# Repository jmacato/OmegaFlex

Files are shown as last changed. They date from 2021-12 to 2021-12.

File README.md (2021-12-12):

# OmegaFlex
A combined NAND/GPU signal/U10 relocation flexible PCB for Nintendo Wii revision 40/60

This flexible PCB combines the goodness of NAND, Wii's GPU signals and the U10 in one package. It also has breakouts for GameCube controller 1/2 data lines with pull up resistors, MODE pin pullup solder bridge pad and USB/Bluetooth data lines as well.

Its primary goal is to reduce the mess of magnet wires in portables and to make the Wii as something of a removable module that can be reused without resoldering when you want to upgrade your portables in the future.

PCBWay can fabricate this easily as well. Kinda expensive though and the ideal number of flex per batch is 25 pcs. But it's so worth it :)

## BitBuilt Thread
https://web.archive.org/web/20211211042716/https://bitbuilt.net/forums/index.php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

## Licensing

This project is covered under the terms of CERN Open Hardware Licence Version 2 - Strongly Reciprocal. This license mandates that any modifications or re-derivations of this project shall be attributed back under the same license and published as well.

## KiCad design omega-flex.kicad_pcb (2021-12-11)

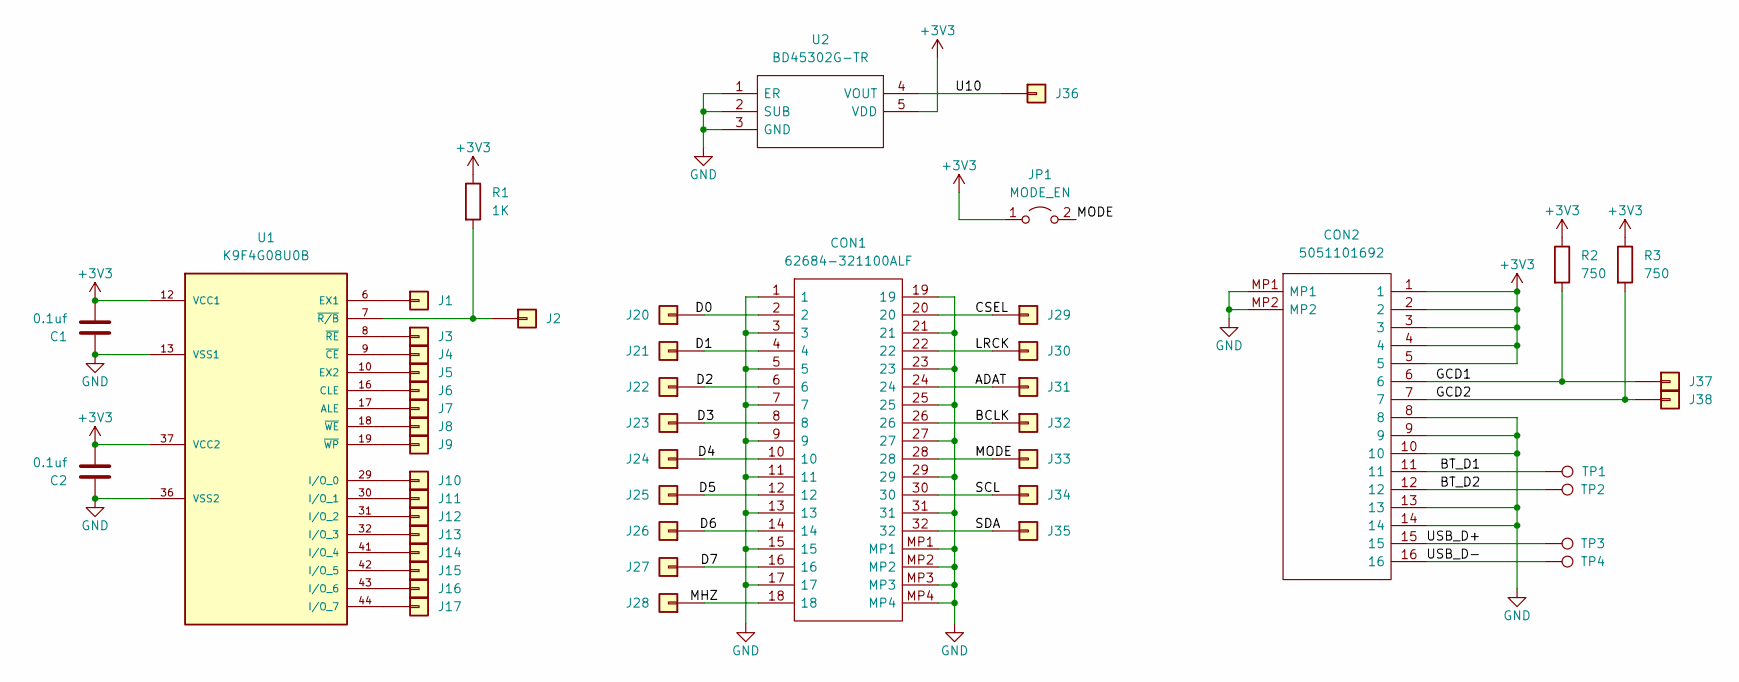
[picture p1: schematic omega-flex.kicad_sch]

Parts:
C1, C2: 0.1uf; C_0402_1005Metric_Pad0.74x0.62mm_HandSolder
CON1: 62684-321100ALF; 62684321100ALF; Manufacturer_Part_Number 62684-321100ALF; Mouser Part Number 649-62684-321100ALF
CON2: 5051101692; Manufacturer_Part_Number 5051101692
J1, J2, J3, J4, J5, J6, J7, J8, J9, J10, J11, J12, J13, J14, J15, J16, J17, J20, J21, J22, J23, J24, J25, J26, J27, J28, J29, J30, J31, J32, J33, J34, J35, J36, J37, J38: Conn_01x01; wii-single-via-0.45mm
JP1: MODE_EN; SolderJumper-2_P1.3mm_Open_Pad1.0x1.5mm
R1: 1K; R_0402_1005Metric_Pad0.72x0.64mm_HandSolder
R2, R3: 750; R_0402_1005Metric_Pad0.72x0.64mm_HandSolder
TP1, TP2, TP3, TP4: TestPoint; TestPoint_Pad_D1.5mm
U1: K9F4G08U0B; Wii-TSOP48-trimmed; MPN S34ML02G100TFI000
U2: BD45302G-TR; SOT95P280X125-5N; Manufacturer_Part_Number BD45302G-TR; Mouser Part Number 755-BD45302G-TR

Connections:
+3V3: C1.2, C2.2, CON2.1, CON2.2, CON2.3, CON2.4, CON2.5, JP1.1 (A), R1.1, R2.1, R3.1, U1.12 (VCC1), U1.37 (VCC2), U2.5 (VDD)
/ADAT: CON1.24, J31.1
/BCLK: CON1.26, J32.1
/BT_D1: CON2.11, TP1.1
/BT_D2: CON2.12, TP2.1
/CSEL: CON1.20, J29.1
/D0: CON1.2, J20.1
/D1: CON1.4, J21.1
/D2: CON1.6, J22.1
/D3: CON1.8, J23.1
/D4: CON1.10, J24.1
/D5: CON1.12, J25.1
/D6: CON1.14, J26.1
/D7: CON1.16, J27.1
/GCD1: CON2.6, J37.1, R2.2
/GCD2: CON2.7, J38.1, R3.2
/LRCK: CON1.22, J30.1
/MHZ: CON1.18, J28.1
/MODE: CON1.28, J33.1, JP1.2 (B)
/SCL: CON1.30, J34.1
/SDA: CON1.32, J35.1
/U10: J36.1, U2.4 (VOUT)
/USB_D+: CON2.15, TP3.1
/USB_D-: CON2.16, TP4.1
GND: C1.1, C2.1, CON1.1, CON1.3, CON1.5, CON1.7, CON1.9, CON1.11, CON1.13, CON1.15, CON1.17, CON1.19, CON1.21, CON1.23, CON1.25, CON1.27, CON1.29, CON1.31, CON1.MP1, CON1.MP2, CON1.MP3, CON1.MP4, CON2.8, CON2.9, CON2.10, CON2.13, CON2.14, CON2.MP1, CON2.MP2, U1.13 (VSS1), U1.36 (VSS2), U2.1 (ER), U2.2 (SUB), U2.3 (GND)
unnamed: J1.1, U1.6 (EX1)
unnamed: J2.1, R1.2, U1.7 (~R/B)
unnamed: J3.1, U1.8 (~RE)
unnamed: J4.1, U1.9 (~CE)
unnamed: J5.1, U1.10 (EX2)
unnamed: J6.1, U1.16 (CLE)
unnamed: J7.1, U1.17 (ALE)
unnamed: J8.1, U1.18 (~WE)
unnamed: J9.1, U1.19 (~WP)
unnamed: J10.1, U1.29 (I/O_0)
unnamed: J11.1, U1.30 (I/O_1)
unnamed: J12.1, U1.31 (I/O_2)
unnamed: J13.1, U1.32 (I/O_3)
unnamed: J14.1, U1.41 (I/O_4)
unnamed: J15.1, U1.42 (I/O_5)
unnamed: J16.1, U1.43 (I/O_6)
unnamed: J17.1, U1.44 (I/O_7)

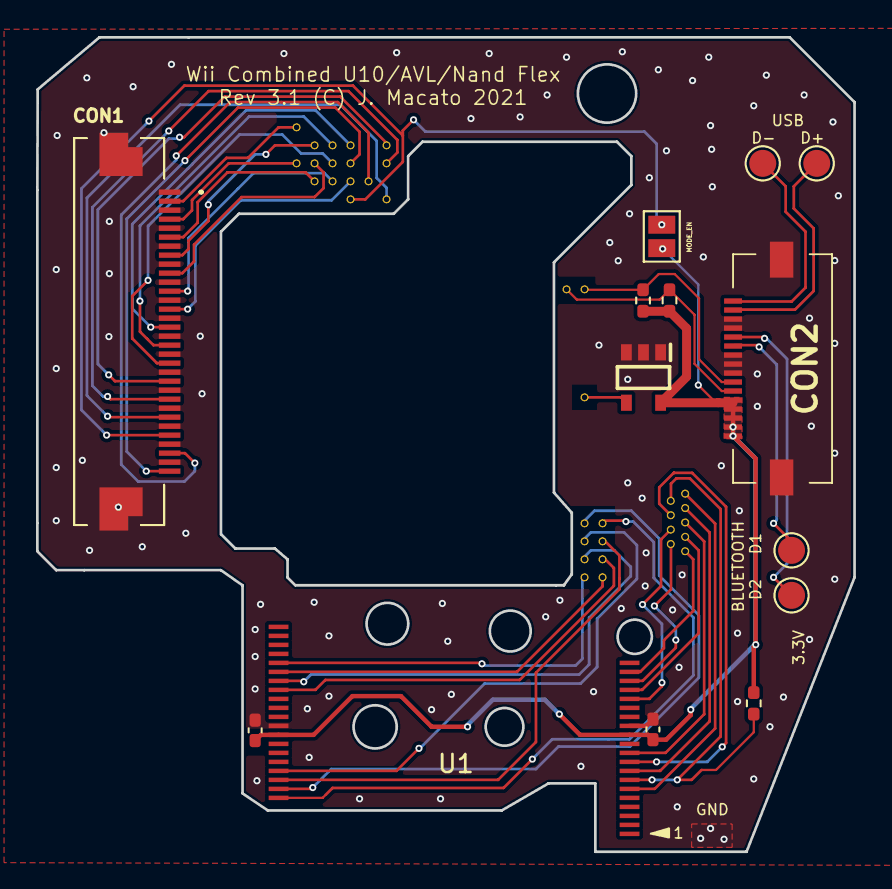
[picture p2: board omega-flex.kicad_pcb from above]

Board: 2 copper layers, 45.4 x 45.2 mm, 50 parts (0 on the bottom side), 42 nets.
